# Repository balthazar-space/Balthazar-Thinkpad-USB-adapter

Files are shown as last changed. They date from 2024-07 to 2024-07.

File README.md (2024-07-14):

# Balthazar Thinkpad USB adapter

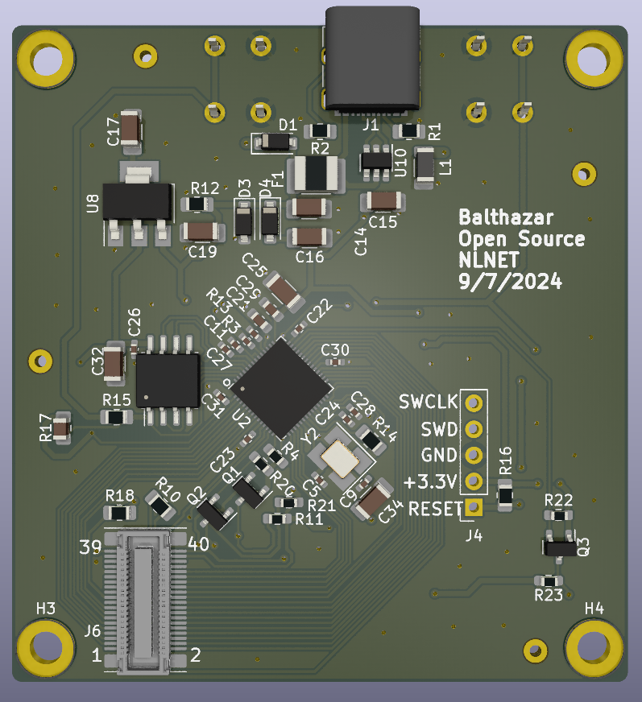
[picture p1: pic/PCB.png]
Adapter


# About

This project will make a USB keyboard/Trackpoint controller and enclosure for the non-chiclet Thinkpad keyboard (from the 10/20 generation, such as the T410, W520, X230 etc.). 

[Keyboard 3](https://github.com/balthazar-space/Balthazar-Keyboard-3) and the Thinkpad over this adapter connect over a USB cable to the Balthazar Unifying board.

https://github.com/balthazar-space/Unifying-PCB

That will give users more options for customizations, and also the possibility to reuse some old Thinkpad keyboards.

You can also use this adapter to connect the Thinkpad keyboard on your PC,  connect the keyboard to the adapter, and use USBC for connection with your PC.

# Controller

The current plan is to use an RP2040 microcontroller running custom QMK to handle the key matrix scanning and Trackpoint.

# Project origin

Differences from the original project:

We have removed parts that the Balthazar Keyboard does not need.

We have removed the USB HUB on the board as we already have HUB on the unifying board. 

We only need one USB TYPE C connector, so we have removed the second one.

We have removed parts, and we made the PCB smaller.

Removing parts will lower production costs.

You can check the original project here: 

https://github.com/bluepylons/A-Thinkpad-USB-keyboard

Here you can find new [BOM](https://github.com/balthazar-space/Balthazar-Thinkpad-USB-adapter/tree/main/PCB/bom)

Adapter is stil not produced, but we should have some prototypes soon!

## License

CERN Open Hardware Licence Version 2 - Weakly Reciprocal

## Funding

This project is funded through the [NGI Zero Entrust Fund](https://nlnet.nl/entrust), a fund
established by [NLnet](https://nlnet.nl) with financial support from the European Commission's
[Next Generation Internet](https://ngi.eu) program. Learn more on the [NLnet project page](https://nlnet.nl/project/Balthazar-Casing/).

[NLNet foundation logo](https://nlnet.nl)
[NGI0 Entrust Logo](https://nlnet.nl/entrust)

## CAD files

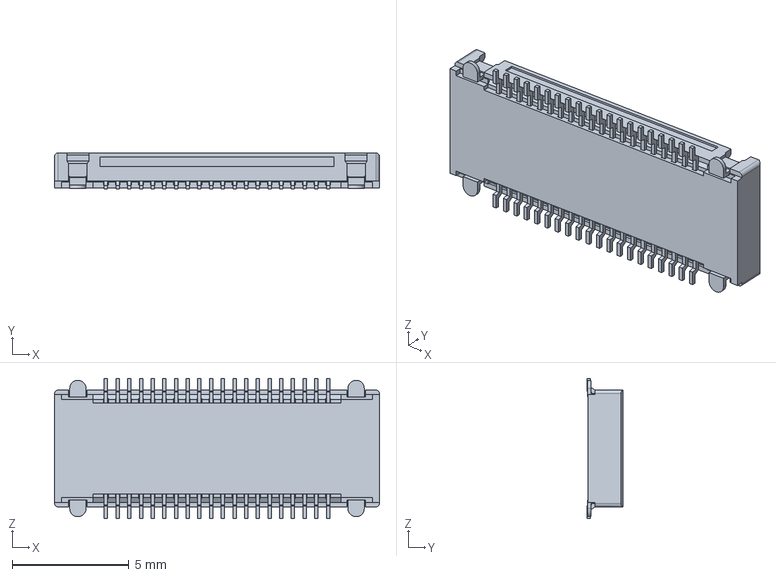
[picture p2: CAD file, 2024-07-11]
PCB/3D/LIB_54363-0489/54363-0489/3D/54363-0489.stp
13.9 x 1.55 x 6.00 mm

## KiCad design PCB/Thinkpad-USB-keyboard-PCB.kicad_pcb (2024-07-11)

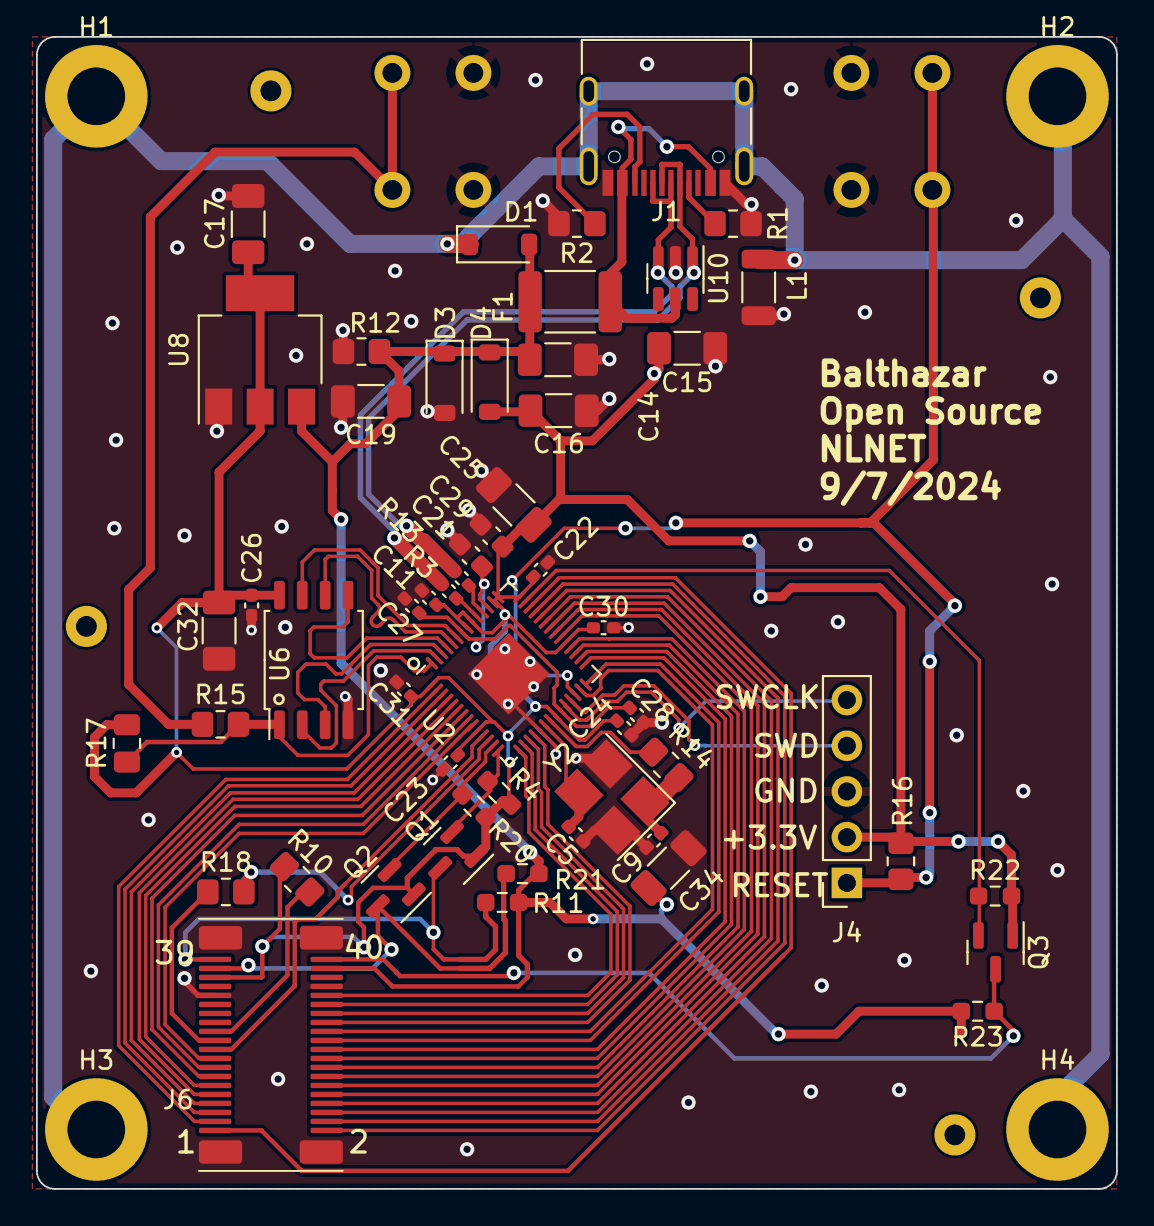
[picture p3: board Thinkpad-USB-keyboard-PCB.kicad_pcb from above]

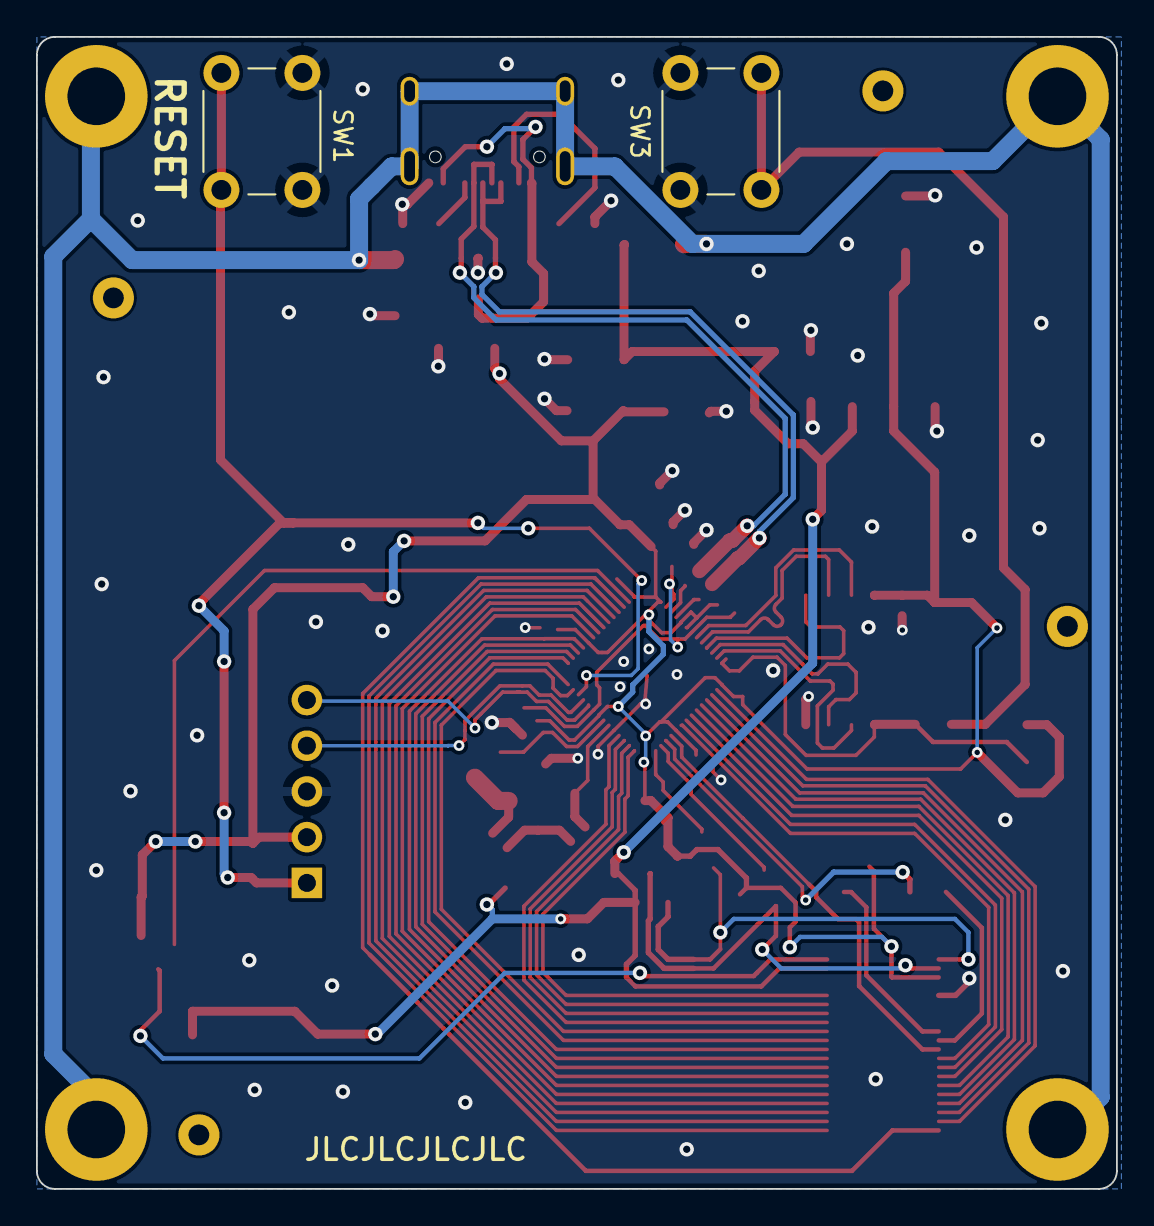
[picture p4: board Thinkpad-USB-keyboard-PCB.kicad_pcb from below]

Board: 4 copper layers, 60.0 x 64.0 mm, 64 parts (2 on the bottom side), 60 nets.

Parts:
C5, C9: 22pF; C_0402_1005Metric_Pad0.74x0.62mm_HandSolder
C11, C22, C23, C24, C26, C27, C28, C30, C31: 100nF; C_0402_1005Metric_Pad0.74x0.62mm_HandSolder
C14, C15, C16, C17, C19, C25, C32, C34: 10uF; C_1206_3216Metric_Pad1.33x1.80mm_HandSolder
C21, C29: 1uF; C_0603_1608Metric_Pad1.08x0.95mm_HandSolder
D1: SMF9.0CA; D_SOD-123
D3, D4: RB060M-60TR; D_SOD-123
F1: 1812L075PR; Fuse_1812_4532Metric_Pad1.30x3.40mm_HandSolder
H1, H2, H3, H4: MountingHole_Pad; MountingHole_3.2mm_M3_ISO7380_Pad
H9, H10, H11, H12: MountingHole; JLCPCB-tooling-hole
J1: USB_C_Receptacle_USB2.0; USB_C_Receptacle_HRO_TYPE-C-31-M-12
J4: SWD; PinSocket_1x05_P2.54mm_Vertical
J6: Conn_02x20_Odd_Even_MountingPin; Molex Slimstack 54363-0489
L1: 60R@100MHz; L_1206_3216Metric
Q1, Q2, Q3: BSS138; SOT-23
R1, R2: 5.1k; R_0805_2012Metric_Pad1.20x1.40mm_HandSolder
R3, R13: 27; C_0402_1005Metric_Pad0.74x0.62mm_HandSolder
R4, R11, R20, R21, R22, R23: 10K; R_0603_1608Metric_Pad0.98x0.95mm_HandSolder
R10, R18: 100; R_0805_2012Metric_Pad1.20x1.40mm_HandSolder
R12: 100k; R_0805_2012Metric_Pad1.20x1.40mm_HandSolder
R14, R15, R16: 1K; R_0805_2012Metric_Pad1.20x1.40mm_HandSolder
R17: DNI; C_0805_2012Metric_Pad1.18x1.45mm_HandSolder
SW1, SW3: SW_Push; SW_PUSH_6mm_H5mm
U2: RP2040; QFN-56-1EP_7x7mm_P0.4mm_EP3.2x3.2mm
U6: W25Q128JVS; SOIC-8_5.23x5.23mm_P1.27mm
U8: TLV1117-33; SOT-223-3_TabPin2
U10: SRV05-4; SOT-23-6
Y2: 12MHz; Crystal_SMD_3225-4Pin_3.2x2.5mm_HandSoldering

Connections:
+1V1: C21.1, C27.1, C28.1, U2.23 (DVDD), U2.45 (VREG_VOUT), U2.50 (DVDD)
+3V3: C11.1, C15.1, C16.1, C17.1, C22.1, C23.1, C24.1, C25.1, C26.1, C29.1, C30.1, C31.1, C32.1, D4.2 (A), J4.2, J6.35, Q1.1 (G), Q2.1 (G), Q3.1 (G), R4.2, R10.2, R16.2, R17.2, R20.2, R22.2, U2.1 (IOVDD), U2.10 (IOVDD), U2.22 (IOVDD), U2.33 (IOVDD), U2.42 (IOVDD), U2.43 (ADC_AVDD), U2.44 (VREG_IN), U2.48 (USB_VDD), U2.49 (IOVDD), U6.8 (VCC), U8.2 (VO)
+5V: C14.1, C19.1, C34.1, D1.2 (A2), D3.1 (K), D4.1 (K), F1.2, J6.38, R11.2, R12.2, R21.2, R23.2, U8.3 (VI)
/~USB_BOOT: R15.1, SW3.2
CS: R15.2, R17.1, U2.56 (QSPI_SS), U6.1 (~CS)
DRV0: J6.22, U2.28 (GPIO17)
DRV1: J6.18, U2.30 (GPIO19)
DRV2: J6.14, U2.32 (GPIO21)
DRV3: J6.10, U2.35 (GPIO23)
DRV4: J6.2, U2.39 (GPIO27_ADC1)
DRV5: J6.4, U2.38 (GPIO26_ADC0)
DRV6: J6.8, U2.36 (GPIO24)
DRV7: J6.12, U2.34 (GPIO22)
DRV8: J6.6, U2.37 (GPIO25)
DRV9: J6.20, U2.29 (GPIO18)
DRV10: J6.16, U2.31 (GPIO20)
DRV11: J6.24, U2.27 (GPIO16)
DRV12: J6.28, U2.17 (GPIO14)
DRV13: J6.32, U2.15 (GPIO12)
DRV14: J6.26, U2.18 (GPIO15)
DRV15: J6.30, U2.16 (GPIO13)
DUP+: J1.A6 (D+), J1.B6 (D+), R3.1, U10.3 (IO2)
DUP-: J1.A7 (D-), J1.B7 (D-), R13.1, U10.1 (IO1)
GND: C5.1, C9.1, C11.2, C14.2, C15.2, C16.2, C17.2, C19.2, C21.2, C22.2, C23.2, C24.2, C25.2, C26.2, C27.2, C28.2, C29.2, C30.2, C31.2, C32.2, C34.2, D3.2 (A), J1.A1 (GND), J1.A12 (GND), J1.B1 (GND), J1.B12 (GND), J4.3, J6.31, J6.34, J6.MP (MountPin), L1.1, R1.2, R2.2, R12.1, SW1.1, SW3.1, U2.19 (TESTEN), U2.57 (GND), U6.4 (GND), U8.1 (GND), U10.2 (VN), Y2.2, Y2.4
GNDPWR: D1.1 (A1), H1.1, H2.1, H3.1, H4.1, J1.S1 (SHIELD), L1.2
HOTKEY: J6.1, U2.40 (GPIO28_ADC2)
LED-CAPS-LOCK: J6.21, R18.1
LED-POWER: J6.23, R10.1
unnamed: C9.2, R14.1, Y2.1
unnamed: J1.A5 (CC1), R1.1
unnamed: J1.B5 (CC2), R2.1
unnamed: R18.2, U2.12 (GPIO9)
unnamed: R13.2, U2.46 (USB_DM)
unnamed: R3.2, U2.47 (USB_DP)
unnamed: C5.2, U2.20 (XIN), Y2.3
unnamed: R14.2, U2.21 (XOUT)
PWRSWITCH: J6.19, U2.11 (GPIO8)
QSPI_CLK: U2.52 (QSPI_SCLK), U6.6 (CLK)
RESET: J4.1, R16.1, SW1.2, U2.26 (RUN)
SD0: U2.53 (QSPI_SD0), U6.5 (DI(IO0))
SD1: U2.55 (QSPI_SD1), U6.2 (DO(IO1))
SD2: U2.54 (QSPI_SD2), U6.3 (IO2)
SD3: U2.51 (QSPI_SD3), U6.7 (IO3)
SENSE0: J6.5, U2.3 (GPIO1)
SENSE1: J6.13, U2.7 (GPIO5)
SENSE2: J6.9, U2.5 (GPIO3)
SENSE3: J6.7, U2.4 (GPIO2)
SENSE4: J6.11, U2.6 (GPIO4)
SENSE5: J6.3, U2.2 (GPIO0)
SENSE6: J6.15, U2.8 (GPIO6)
SENSE7: J6.17, U2.9 (GPIO7)
SWCLK: J4.5, U2.24 (SWCLK)
SWD: J4.4, U2.25 (SWD)
TP4-CLK-3V3: Q1.2 (S), R4.1, U2.14 (GPIO11)
TP4-CLK-5V: J6.39, Q1.3 (D), R11.1
TP4-DATA-3V3: Q2.2 (S), R20.1, U2.13 (GPIO10)
TP4-DATA-5V: J6.37, Q2.3 (D), R21.1
TP4-RESET-3V3: Q3.2 (S), R22.1, U2.41 (GPIO29_ADC3)
TP4-RESET-5V: J6.40, Q3.3 (D), R23.1
VBUS: F1.1, J1.A4 (VBUS), J1.A9 (VBUS), J1.B4 (VBUS), J1.B9 (VBUS), U10.5 (VP)
